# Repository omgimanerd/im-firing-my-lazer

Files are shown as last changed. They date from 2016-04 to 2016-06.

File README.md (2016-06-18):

# im-firing-my-lazer
This repository contains code used in our Modern Physics Laser Scanning Project
conducted in 2016 at Stuyvesant High School.

# Dependencies
To replicate this experiment with our Arduino setup, this project requires
pyserial.
```
pip install pyserial
```

To run the analyses on the data or to view the data, you need numpy, matplotlib, and pillow.
```
pip install numpy matplotlib pillow
```

# Experiment explanation and results
Please reference this [paper](https://github.com/omgimanerd/im-firing-my-lazer/blob/master/paper/paper.pdf)

# Creators/Authors
  - omgimanerd (Alvin Lin)
  - sachalmalick (Sachal Malick)
  - jijiglobe (Jion Fairchild)

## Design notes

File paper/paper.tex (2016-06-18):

\documentclass[letterpaper, 12pt]{article}
\renewcommand{\refname}{References and Resources}
\usepackage[utf8]{inputenc}
\usepackage{float}
\usepackage{graphicx}
\graphicspath{{pictures/}}
\usepackage{listings}
\usepackage{pgfplots}
\pgfplotsset{compat=1.9}
\usepackage[pdf]{pstricks}
\usepackage{pst-optexp}
\usepackage{hyperref}
\hypersetup{colorlinks=true,linkcolor=blue,filecolor=magenta,urlcolor=cyan}

\setlength{\parskip}{1em}

\title{Modern Physics Laser Scanning Project}
\author{Alvin Lin
  \thanks{with Jion Fairchild and Sachal Malick}}
\date{June 2016}

\begin{document}

\begin{titlepage}
\maketitle
\end{titlepage}

\begin{abstract}
This experiment was conducted in the Modern Physics class of 2016 at Stuyvesant High School. The goal was to build a laser scanner using a laser and a photometer to find its maximum achievable resolution.
\end{abstract}

\section{Experimental Setup}
\par
In this experiment, we focused a laser onto a piece of paper containing our
scanning sample and read the amount of reflected light using a photometer. The photometer displayed the amount of light it received on a digital display but also conveniently had two banana jacks that outputted a voltage proportional to the amount of light it received. This allowed us to connect an Arduino microcontroller to the photometer to read and store the voltages as we passed the scanning sample beneath the laser. To shift the sample vertically and horizontally during scanning, we 3D printed slides which we actuated using stepper motors.
\par
In order to maximize the resolution of our image, we wanted the laser beam to be as small and as focused as possible. We spaced three concave lenses in front of the laser to expand the beam, collimate it, and focus it to a point. The scanning sample would be placed at the focal point of the last concave lense. If the laser was focused on a darker point on the sample, it would reflect less light and the photometer would read a lower voltage. Conversely, if the laser was focused on a lighter point, it would reflect more light and the photometer would read a higher voltage.

\begin{pspicture}[](0,0)(14,4)
  \pnodes(2,2){A}(12,2){B}
  \pnodes(10.5,1.5){D}(10.7,2){E}(10.9,2.5){F}
  \begin{optexp}
    \optbox[position=start](A)(B){laser}
    \lens[lensradius=0.75,abspos=1,labeloffset=-1](A)(B){expands beam}
    \lens[lensradius=2.3,abspos=4](A)(B){collimates beam}
    \lens[lensradius=0.75,abspos=8](A)(B){focuses beam}
    \mirror[labeloffset=-0.7](D)(E)(F){sample}
    \drawwidebeam[beamwidth=0.2,linecolor=red]{-}(B)
  \end{optexp}
\end{pspicture}

\par
The Arduino that we used to read in the voltage values from the photometer was also used to simultaneously control the stepper motors moving the sample. For one dimensional scans, we scanned across the sample once and graphed the relative intensities as the laser passed over the sample. For two dimensional scans, we oscillated the sample in one direction while shifting it perpendicular to its direction of oscillation and mapped the relative intensies onto a 2D grid.

\begin{figure}[H]
  \centering
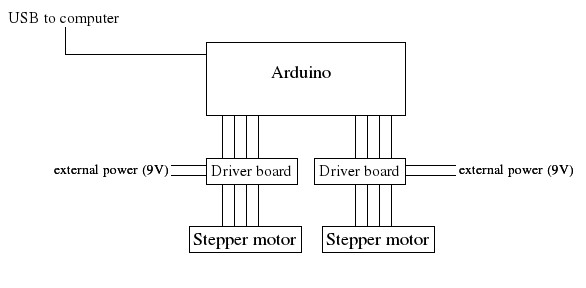
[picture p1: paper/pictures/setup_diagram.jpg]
  
  \caption{Diagram of Components}
\end{figure}

\newpage

\begin{figure}[H]
  \centering
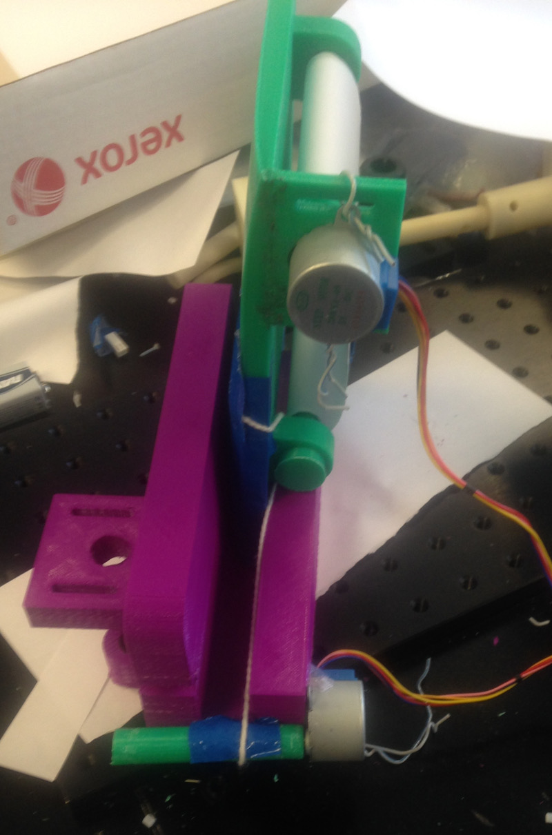
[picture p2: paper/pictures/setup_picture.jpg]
  
  \caption[caption]{3D printed components\footnotemark}
\end{figure}
\footnotetext{CADs available here:\cite{github}}

\section{Experimental Procedure}
\par
We set up various resolution test targets beneath our scanner and ran our scanner over each target. Based on the stepper motors\footnotemark
\footnotetext{USPRO 28BYJ 5V 4-phase 5-wire stepper motors \cite{amazon}}
and driver boards\footnotemark
\footnotetext{ULN2003 driver board for Arduino \cite{amazon}}
we were using, we approximated what the resolution of our setup would be. Due to the driver board's microstepping, each revolution of the motor took 512 steps. With a 0.5 inch diameter drive axle moving the sample, this means that 1 step of the motor would shift the sample $3.067962\times10^{-3}$ inches. Converting this to $\frac{lines}{mm}$:

$$ 3.067962\times10^{-3}in = 7.79262348\times10^{-2}mm $$
$$ \frac{1\ line}{7.79262348\times10^{-2}mm} \approx 12.83\frac{lines}{mm} $$

\par
This number only holds true if our laser beam is an infinitesimally small point. Since this is not the case, our actual resolution is much lower.

\section{Experimental Results for 1 Dimensional Scans}

\begin{figure}[H]
  \centering
  
  \caption[caption]{Example Resolution Test Targets (not to scale)\cite{test_chart}}
\end{figure}

\par
Running the laser scanner over the actual resolution test targets above gave us a much clearer indicator of whether or not our scanner was actually able to resolve up to 12.83 $\frac{lines}{mm}$. We ran the laser directly over the five lines in each resolution test target while reading in the values, starting with the lowest resolution.

\pgfplotstableread{scan_1.6.txt}
  \dataone
\begin{figure}[H]
  \centering
  \begin{tikzpicture}
    \begin{axis}[
      xlabel={$time$},
      ylabel={$relative\ intensity$},
      xticklabels={,,},
      yticklabels={,,}]
      \addplot[mark=none] table from \dataone;
    \end{axis}
  \end{tikzpicture}
  \caption[caption]{Scan of 1.6 $\frac{lines}{mm}$ resolution test target}
\end{figure}

\par
In figure 4, five discrete dips in the relative intensity read by the Arduino are visible as the laser passes over the 1.6 $\frac{lines}{mm}$ resolution test target. Each dip is distinguishable and corresponds to a line on the resolution test target. As long as each dip in the relative intensity is discrete for that test, we will consider it a resolvable resolution.

\pgfplotstableread{scan_1.8.txt}
  \datatwo
\begin{figure}[H]
  \centering
  \begin{tikzpicture}
    \begin{axis}[
      xlabel={$time$},
      ylabel={$relative\ intensity$},
      xticklabels={,,},
      yticklabels={,,}]
      \addplot[mark=none] table from \datatwo;
    \end{axis}
  \end{tikzpicture}
  \caption[caption]{Scan of 1.8 $\frac{lines}{mm}$ resolution test target}
\end{figure}

\pgfplotstableread{scan_2.0.txt}
  \datathree
\begin{figure}[H]
  \centering
  \begin{tikzpicture}
    \begin{axis}[
      xlabel={$time$},
      ylabel={$relative\ intensity$},
      xticklabels={,,},
      yticklabels={,,}]
      \addplot[mark=none] table from \datathree;
    \end{axis}
  \end{tikzpicture}
  \caption[caption]{Scan of 2.0 $\frac{lines}{mm}$ resolution test target}
\end{figure}

\pgfplotstableread{scan_2.2.txt}
  \datathree
\begin{figure}[H]
  \centering
  \begin{tikzpicture}
    \begin{axis}[
      xlabel={$time$},
      ylabel={$relative\ intensity$},
      xticklabels={,,},
      yticklabels={,,}]
      \addplot[mark=none] table from \datathree;
    \end{axis}
  \end{tikzpicture}
  \caption[caption]{Scan of 2.2 $\frac{lines}{mm}$ resolution test target}
\end{figure}

\pgfplotstableread{scan_2.5.txt}
  \datathree
\begin{figure}[H]
  \centering
  \begin{tikzpicture}
    \begin{axis}[
      xlabel={$time$},
      ylabel={$relative\ intensity$},
      xticklabels={,,},
      yticklabels={,,}]
      \addplot[mark=none] table from \datathree;
    \end{axis}
  \end{tikzpicture}
  \caption[caption]{Scan of 2.5 $\frac{lines}{mm}$ resolution test target}
\end{figure}

\pgfplotstableread{scan_2.8.txt}
  \datathree
\begin{figure}[H]
  \centering
  \begin{tikzpicture}
    \begin{axis}[
      xlabel={$time$},
      ylabel={$relative\ intensity$},
      xticklabels={,,},
      yticklabels={,,}]
      \addplot[mark=none] table from \datathree;
    \end{axis}
  \end{tikzpicture}
  \caption[caption]{Scan of 2.8 $\frac{lines}{mm}$ resolution test target}
\end{figure}

\pgfplotstableread{scan_3.2.txt}
  \datathree
\begin{figure}[H]
  \centering
  \begin{tikzpicture}
    \begin{axis}[
      xlabel={$time$},
      ylabel={$relative\ intensity$},
      xticklabels={,,},
      yticklabels={,,}]
      \addplot[mark=none] table from \datathree;
    \end{axis}
  \end{tikzpicture}
  \caption[caption]{Scan of 3.2 $\frac{lines}{mm}$ resolution test target}
\end{figure}

\pgfplotstableread{scan_4.0.txt}
  \datathree
\begin{figure}[H]
  \centering
  \begin{tikzpicture}
    \begin{axis}[
      xlabel={$time$},
      ylabel={$relative\ intensity$},
      xticklabels={,,},
      yticklabels={,,}]
      \addplot[mark=none] table from \datathree;
    \end{axis}
  \end{tikzpicture}
  \caption[caption]{Scan of 4.0 $\frac{lines}{mm}$ resolution test target}
\end{figure}

\section{Analysis}
\par
Figures 5 to 11 show our scan data as we increase the resolution of our test target. As the resolution increases, the variance in relative intensity between the lines and the space between them becomes muddled. It is possible to see five discrete dips only up to 3.2 $\frac{lines}{mm}$. At 4.0 $\frac{lines}{mm}$, it is no longer possible to discern five discrete dips in the relative intensity detected. Our testable scanner resolution limit, therefore, is 3.2 $\frac{lines}{mm}$.
\par
We could likely improve our resolution by focusing the laser to a smaller point. Due to human error, our lenses were probably not optimally aligned and we did not focus the laser to a small enough point. Additionally, we could improve the scanner by reducing the radius of the axle pulling the sample across the laser, which would reduce the step distance and increase the precision.

\section{Experimental Results for 2 Dimensional Scans}
\par
For two dimensional scans, instead of running the sample in one direction under the laser, we oscillated it back and forth in the $x$ direction while shifting it in the $y$ direction. This allowed us to produce a two-dimensional image of the lines on the resolution test target by mapping the values onto a 2D grid.

\begin{figure}[H]
  \centering
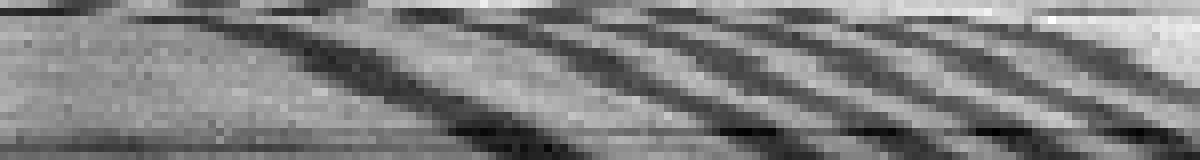
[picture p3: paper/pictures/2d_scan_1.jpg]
  
  \caption[caption]{Two Dimensional Scan of the 1.6 $\frac{lines}{mm}$ Test Target}
\end{figure}

\par
For demonstration purposes, we used a lower resolution test target so that we could produce a discernible image. We scaled the voltage received by the Arduino to a greyscale value and plotted it based on the motor's position to create the image. However, the motor would slightly drift after each oscillation, creating the slanted lines visible in the scan above.

\begin{figure}[H]
  \centering
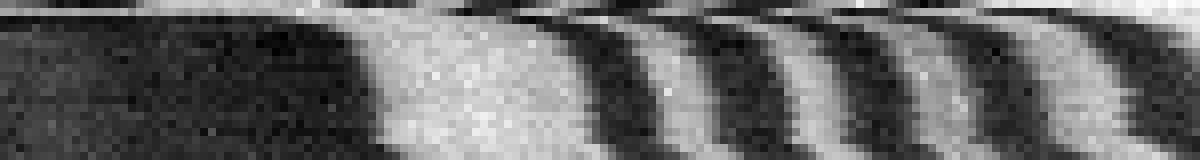
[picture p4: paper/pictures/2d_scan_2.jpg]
  
  \caption[caption]{Two Dimensional Scan with Drift Adjustment}
\end{figure}

\par
We were able to reduce some of the slanting by manually accounting for the drift in the motors. Some noise is visible in both of the scans due to the flexing of test target during scanning since it was printed on standard printer paper.

\newpage

\begin{thebibliography}{9}

  \bibitem{amazon}
  Amazon.
  \textit{USPRO 28BYJ Stepper Motors + ULN2003 Driver Board}
  \texttt{https://www.amazon.com/USPRO-Stepper-28BYJ-48-4-Phase-ULN2003/}
  \texttt{dp/B00JB22IQC}

  \bibitem{arduino}
  Arduino.
  \textit{References and Guides}\newline
  \texttt{https://www.arduino.cc/}

  \bibitem{github}
  GitHub.
  \textit{im-firing-my-lazer repository}
  Alvin Lin, 2016\newline
  \texttt{https://www.github.com/omgimanerd/im-firing-my-lazer}

  \bibitem{laser_scanning_paper}
  Peter Axelsson.
  \textit{Processing of laser scanner data - algorithms and applications}.
  Department of Geodesy and Photogrammetry, Royal Institute of Technology, Stockholm, Sweden, 1998.\newline
  \texttt{http://warnercnr.colostate.edu/~lefsky/isprs/1133.pdf}

  \bibitem{thinkquest}
  ThinkQuest.
  \textit{Lenses and optics}
  American Physical Society, 2006\newline
  \texttt{http://www.physicscentral.com/experiment/physicsquest/past/upload/}
  \texttt{pq06-Extension4.pdf}

  \bibitem{test_chart}
  USAF Test Chart
  \textit{High Definition Test Slides}
  Pyser-SGI\newline
  \texttt{http://www.pyser-sgi.com/graticules/graticules-news/usaf-test-chart-}
  \texttt{gets-higher-definition}

\end{thebibliography}

\newpage

\appendix
\section{Appendix A: Code Resources}

\subsection{Arduino code for 1 dimensional scanning}
\begin{lstlisting}[language=C]
#include <Stepper.h>

// Globals
#define BAUDRATE 9600
#define NUM_POLLS 10

#define SCAN_SPEED 60
#define SCAN_STEPS 700
#define SCAN_INTERVAL 1

Stepper motor(512, 8, 10, 9, 11);

void setup() {
  Serial.begin(BAUDRATE);
  for (int i = 8; i < 12; ++i) {
    pinMode(i, OUTPUT);
  }
  motor.setSpeed(SCAN_SPEED);
}

void loop() {
  String data = Serial.readString();
  float value_sum = 0;
  Serial.println(data);
  if (data == "begin") {
    Serial.println("{ \"type\": \"1d\" }");
    for (int i = 0; i < SCAN_STEPS; ++i) {
      value_sum = 0;
      for (int j = 0; j < NUM_POLLS; ++j) {
        value_sum += analogRead(A0);
      }
      Serial.println(value_sum / 10.0);
      motor.step(SCAN_INTERVAL);
    }
    Serial.println("end");
    motor.step(-SCAN_INTERVAL * SCAN_STEPS);
  }
}
\end{lstlisting}

\subsection{Arduino code for 2 dimensional scanning}
\begin{lstlisting}[language=C]
#include <Stepper.h>

// Globals
#define BAUDRATE 9600
#define NUM_POLLS 10

#define SCAN_SPEED 40
#define X_SCAN_STEPS 20
#define X_SCAN_INTERVAL 50
#define Y_SCAN_STEPS 150
#define Y_SCAN_INTERVAL 5

// The motor drifts some amount every y-iteration. This constant fights against that.
#define DRIFT_CONSTANT -50

Stepper x_motor(512, 4, 6, 5, 7);
Stepper y_motor(512, 8, 10, 9, 11);

void setup() {
  Serial.begin(BAUDRATE);
  for (int i = 4; i < 12; ++i) {
    pinMode(i, OUTPUT);
  }
  x_motor.setSpeed(SCAN_SPEED);
  y_motor.setSpeed(SCAN_SPEED);
}

void loop() {
  String data = Serial.readString();
  float value_sum = 0;
  Serial.println(data);
  if (data == "begin") {
    Serial.print("{ \"type\": \"2d\", \"width\": ");
    Serial.print(Y_SCAN_STEPS);
    Serial.print(", \"height\": ");
    Serial.print(X_SCAN_STEPS);
    Serial.print(" }\n");
    for (int x = 0; x < X_SCAN_STEPS; ++x) {
      for (int y = 0; y < Y_SCAN_STEPS; ++y) {
        value_sum = 0;
        for (int i = 0; i < NUM_POLLS; ++i) {
          value_sum += analogRead(A0);
          delay(2);
        }
        Serial.println(value_sum / 10.0);
        y_motor.step(Y_SCAN_INTERVAL);
      }
      y_motor.step(-(Y_SCAN_INTERVAL * Y_SCAN_STEPS - DRIFT_CONSTANT));
      x_motor.step(X_SCAN_INTERVAL);
    }
    Serial.println("end");
    x_motor.step(-X_SCAN_INTERVAL * X_SCAN_STEPS);
    y_motor.step(-Y_SCAN_INTERVAL * Y_SCAN_STEPS);
  }
}
\end{lstlisting}

\subsection{Python code to visualize the stored data}
\begin{lstlisting}[language=Python]
#!/usr/bin/python

from matplotlib import pyplot
from PIL import Image

import argparse
import json
import numpy as np

class Visualizer:

    @staticmethod
    def visualize(data):
        visualize_functions = {
            "1d": Visualizer.visualize_1d,
            "2d": Visualizer.visualize_2d
        }
        visualize_functions[data["type"]](data)

    @staticmethod
    def visualize_1d(data):
        figure = pyplot.figure()
        figure.suptitle("Intensity vs motor ticks")
        values = data["values"]
        pyplot.plot(range(len(values)), values)
        pyplot.xlabel("Motor ticks")
        pyplot.ylabel("Relative Intensity")
        pyplot.grid()
        pyplot.show()

    @staticmethod
    def _linear_scale(x, a1, a2, b1, b2):
        return ((x - a1) * (b2 - b1) / (a2 - a1)) + b1

    @staticmethod
    def _to_pil_data(values):
        low, high = min(values), max(values)
        return map(lambda x: Visualizer._linear_scale(x, low, high, 0, 255),
                   values)

    @staticmethod
    def visualize_2d(data):
        width = data["width"]
        height = data["height"]
        image = Image.new("1", (width, height))
        image.putdata(Visualizer._to_pil_data(data["values"]))
        image = image.resize((width * 8, height * 8), Image.ANTIALIAS)
        image.show()

if __name__ == "__main__":
    parser = argparse.ArgumentParser()
    parser.add_argument("filename", help="The JSON file containing the data")
    args = parser.parse_args()
    with open(args.filename) as data_file:
        Visualizer.visualize(json.loads(data_file.read().strip()))
\end{lstlisting}

\subsection{Python code to read the data from the serial port}
\begin{lstlisting}
#!/usr/bin/python

from lib.visualizer import Visualizer

import argparse
import json
import serial
import sys
import time

class Scanner():

    BAUDRATE = 9600
    AMPLIFYING_FACTOR = 3

    def __init__(self, serial):
        self.serial = serial

    @staticmethod
    def create(location):
        return Scanner(serial.Serial(location, Scanner.BAUDRATE))

    def read(self):
        return self.serial.readline().strip()

    def write(self, data):
        self.serial.write(data)

    def read_laser_info(self):
        data = {}
        values = []
        read = None
        while read != "begin":
            self.write("begin")
            read = self.read()
        while True:
            read = self.read()
            if read == "end":
                break
            print "Received %s" % read
            try:
                values.append(float(read) * 2)
            except ValueError:
                try:
                    data.update(json.loads(read))
                except:
                    continue
        data.update({
            "values": values
        })
        return data

if __name__ == "__main__":
    argparser = argparse.ArgumentParser()
    argparser.add_argument("serial_port", help="The serial port to read from")
    args = argparser.parse_args()

    print "Generating a scanner data visualization..."
    scanner = Scanner.create(args.serial_port)
    data = scanner.read_laser_info()

    Visualizer.visualize(data)

    print "Type a filename to save, otherwise press enter to exit..."
    filename = raw_input()
    if filename != "":
        with open("data/%s.json" % filename, "w") as f:
            f.write(json.dumps(data))
\end{lstlisting}

\end{document}

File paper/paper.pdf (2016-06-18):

# Modern Physics Laser Scanning Project

### Alvin Lin ∗

### June 2016

∗with Jion Fairchild and Sachal Malick

1

Abstract

This experiment was conducted in the Modern Physics class of 2016 at Stuyvesant High School. The goal was to build a laser scanner using a laser and a photometer to find its maximum achievable resolution.

## 1 Experimental Setup

In this experiment, we focused a laser onto a piece of paper containing our scanning sample and read the amount of reflected light using a photometer. The photometer displayed the amount of light it received on a digital dis-play but also conveniently had two banana jacks that outputted a voltage proportional to the amount of light it received. This allowed us to connect an Arduino microcontroller to the photometer to read and store the voltages as we passed the scanning sample beneath the laser. To shift the sample vertically and horizontally during scanning, we 3D printed slides which we actuated using stepper motors.

In order to maximize the resolution of our image, we wanted the laser beam to be as small and as focused as possible. We spaced three concave lenses in front of the laser to expand the beam, collimate it, and focus it to a point. The scanning sample would be placed at the focal point of the last concave lense. If the laser was focused on a darker point on the sample, it would reflect less light and the photometer would read a lower voltage. Conversely, if the laser was focused on a lighter point, it would reflect more light and the photometer would read a higher voltage.

laser

expands beam

collimates beam | focuses beam sample

The Arduino that we used to read in the voltage values from the photometer was also used to simultaneously control the stepper motors moving the sample. For one dimensional scans, we scanned across the sample once and graphed the relative intensities as the laser passed over the sample. For

1

two dimensional scans, we oscillated the sample in one direction while shifting it perpendicular to its direction of oscillation and mapped the relative intensies onto a 2D grid.

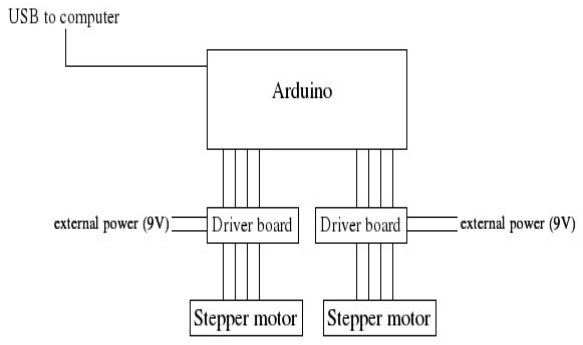
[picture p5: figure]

Figure 1: Diagram of Components

2

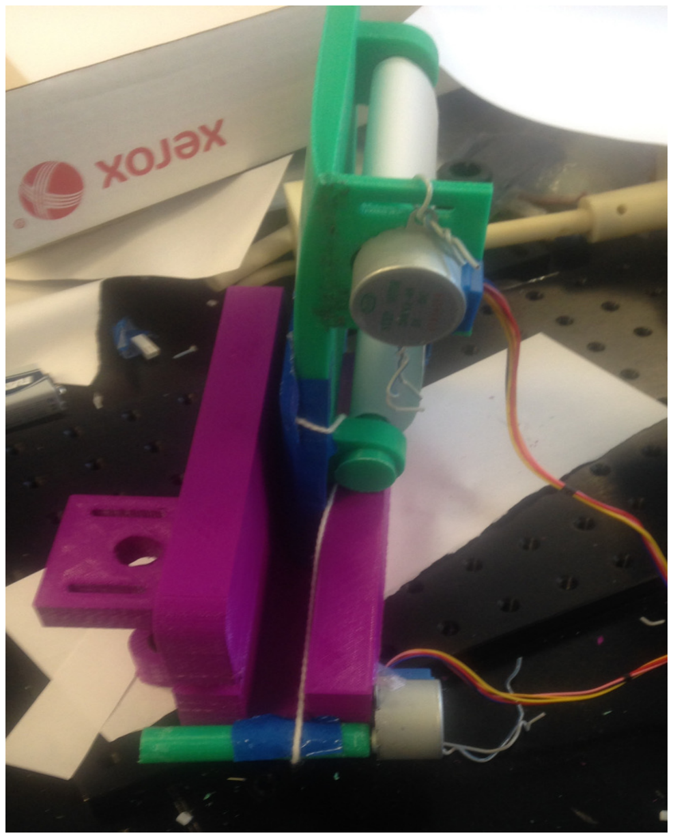
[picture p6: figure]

Figure 2: 3D printed components¹

## 2 Experimental Procedure

We set up various resolution test targets beneath our scanner and ran our scanner over each target. Based on the stepper motors² and driver boards³ we were using, we approximated what the resolution of our setup would be. Due to the driver board’s microstepping, each revolution of the motor took 512 steps. With a 0.5 inch diameter drive axle moving the sample, this means that 1 step of the motor would shift the sample 3.067962×10⁻³ inches.
Converting this to lines
mm

:

1CADs available here:[3]
2USPRO 28BYJ 5V 4-phase 5-wire stepper motors [1] 3ULN2003 driver board for Arduino [1]

3

3.067962 × 10⁻³

in = 7.79262348 × 10⁻²mm

1 line
7.79262348 × 10⁻²mm

≈ 12.83

lines
mm

This number only holds true if our laser beam is an infinitesimally small point. Since this is not the case, our actual resolution is much lower.

## 3 Experimental Results for 1 Dimensional Scans

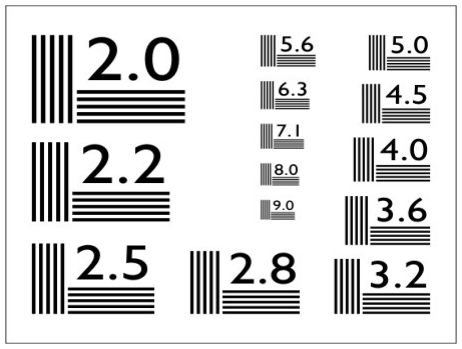
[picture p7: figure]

Figure 3: Example Resolution Test Targets (not to scale)[6]

Running the laser scanner over the actual resolution test targets above gave us a much clearer indicator of whether or not our scanner was actually able to resolve up to 12.83 lines
mm

. We ran the laser directly over the five lines in each resolution test target while reading in the values, starting with the lowest resolution.

4

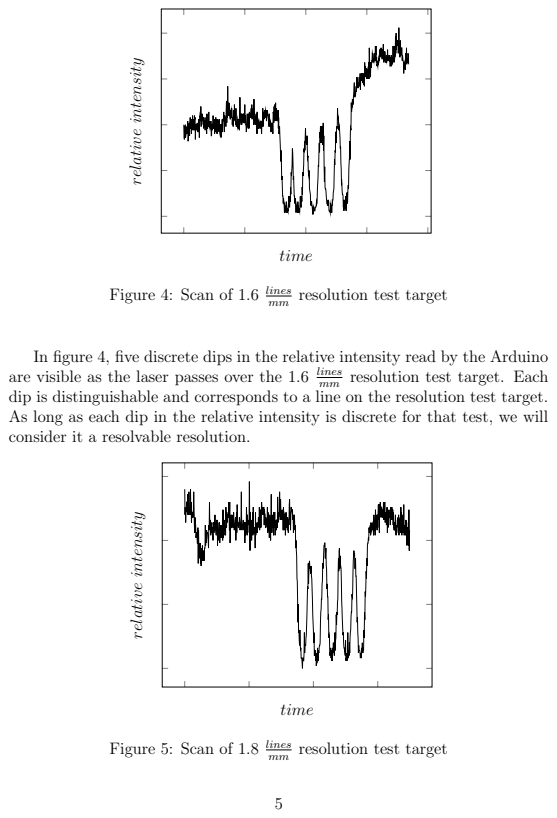
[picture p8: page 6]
time; relative intensity

Figure 4: Scan of 1.6 lines

resolution test target

In figure 4, five discrete dips in the relative intensity read by the Arduino
are visible as the laser passes over the 1.6 lines
dip is distinguishable and corresponds to a line on the resolution test target.
As long as each dip in the relative intensity is discrete for that test, we will
consider it a resolvable resolution.

resolution test target. Each

Figure 5: Scan of 1.8 lines

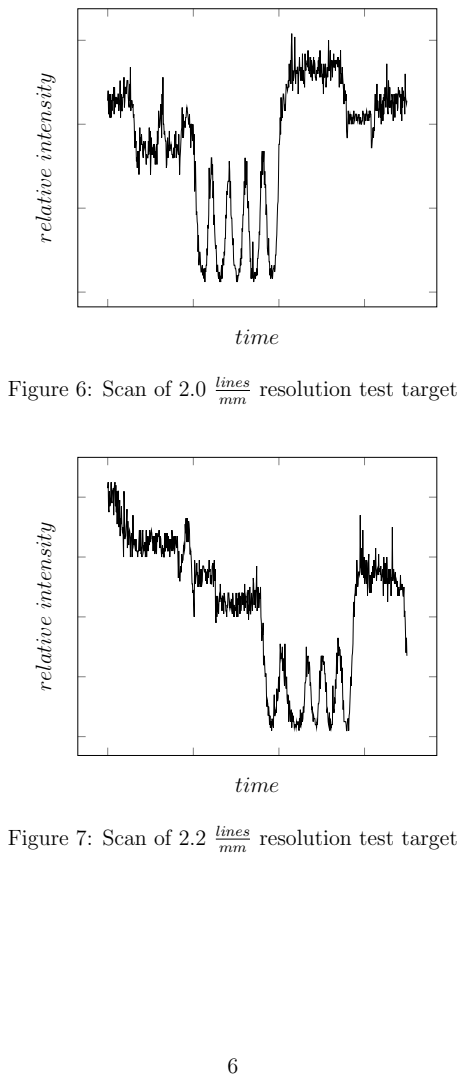
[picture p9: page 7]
time; relative intensity

Figure 6: Scan of 2.0 lines

resolution test target

Figure 7: Scan of 2.2 lines

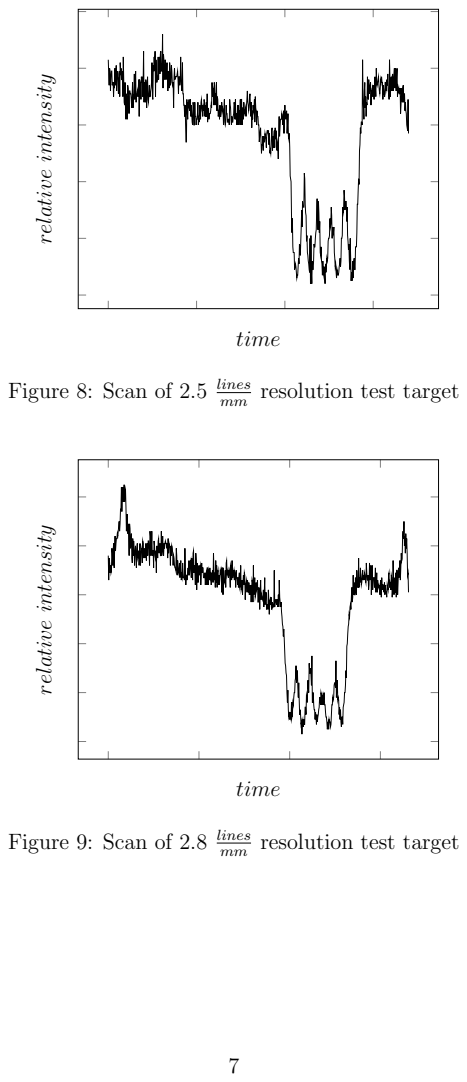
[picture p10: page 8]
time; relative intensity

Figure 8: Scan of 2.5 lines

resolution test target

Figure 9: Scan of 2.8 lines

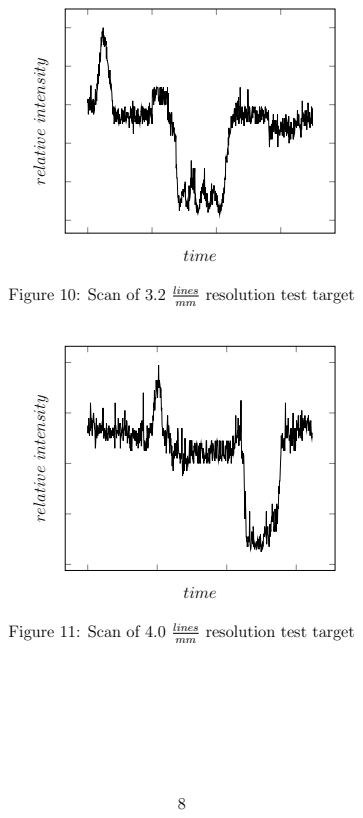
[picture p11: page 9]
time; relative intensity

Figure 10: Scan of 3.2 lines

resolution test target

Figure 11: Scan of 4.0 lines

## 4 Analysis

Figures 5 to 11 show our scan data as we increase the resolution of our test target. As the resolution increases, the variance in relative intensity between the lines and the space between them becomes muddled. It is possible to see five discrete dips only up to 3.2 lines
mm

. At 4.0 lines
mm

, it is no longer possible to discern five discrete dips in the relative intensity detected. Our testable scanner resolution limit, therefore, is 3.2 lines
mm

We could likely improve our resolution by focusing the laser to a smaller point. Due to human error, our lenses were probably not optimally aligned and we did not focus the laser to a small enough point. Additionally, we could improve the scanner by reducing the radius of the axle pulling the sample across the laser, which would reduce the step distance and increase the precision.

## 5 Experimental Results for 2 Dimensional Scans

For two dimensional scans, instead of running the sample in one direction under the laser, we oscillated it back and forth in the x direction while shifting it in the y direction. This allowed us to produce a two-dimensional image of the lines on the resolution test target by mapping the values onto a 2D grid.

9

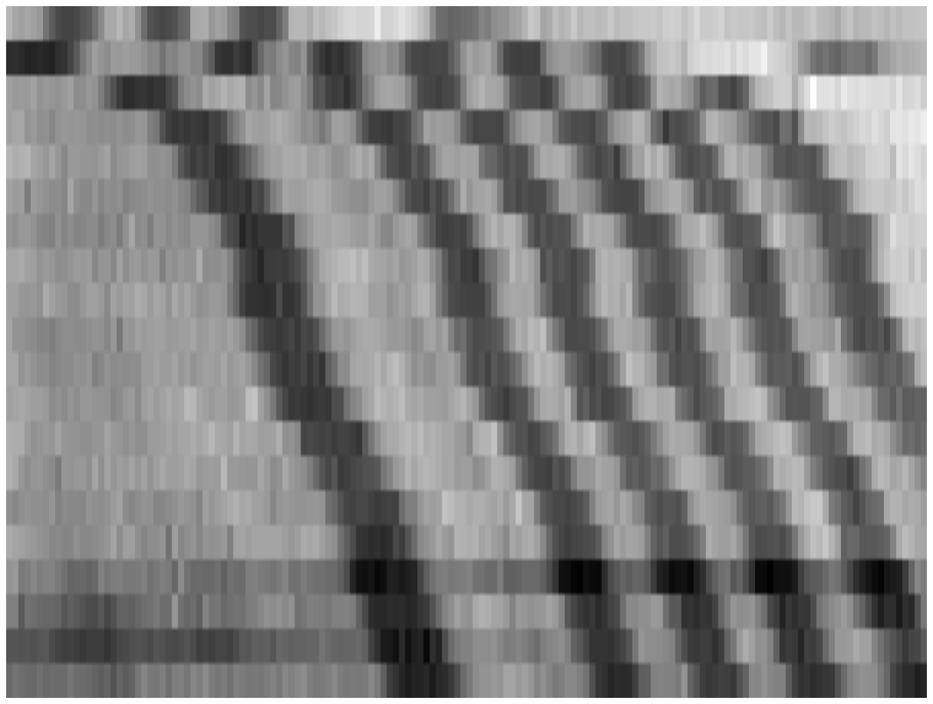
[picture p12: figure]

Figure 12: Two Dimensional Scan of the 1.6 lines
mm Test Target

For demonstration purposes, we used a lower resolution test target so that we could produce a discernible image. We scaled the voltage received by the Arduino to a greyscale value and plotted it based on the motor’s position to create the image. However, the motor would slightly drift after each oscillation, creating the slanted lines visible in the scan above.

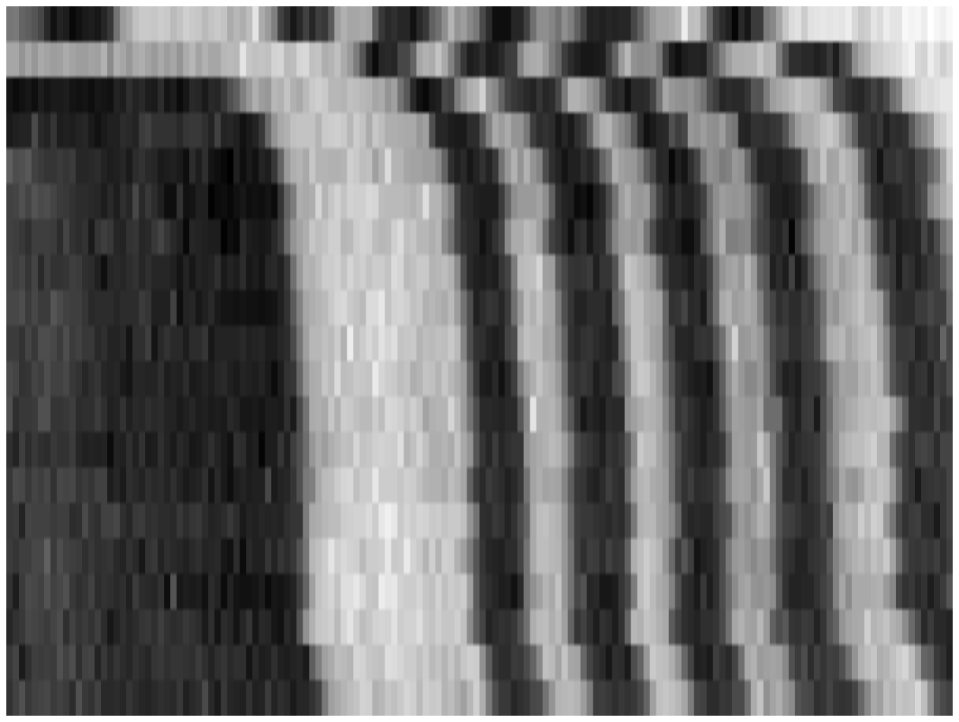
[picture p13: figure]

Figure 13: Two Dimensional Scan with Drift Adjustment

We were able to reduce some of the slanting by manually accounting for

10 the drift in the motors. Some noise is visible in both of the scans due to the flexing of test target during scanning since it was printed on standard printer paper.

11

## References and Resources

[1] Amazon. USPRO 28BYJ Stepper Motors + ULN2003 Driver Board https://www.amazon.com/USPRO-Stepper-28BYJ-48-4-Phase-ULN2003/dp/B00JB22IQC
[2] Arduino. References and Guides
https://www.arduino.cc/
[3] GitHub. im-firing-my-lazer repository Alvin Lin, 2016 https://www.github.com/omgimanerd/im-firing-my-lazer
[4] Peter Axelsson. Processing of laser scanner data - algorithms and appli-cations. Department of Geodesy and Photogrammetry, Royal Institute of Technology, Stockholm, Sweden, 1998. http://warnercnr.colostate.edu/ lefsky/isprs/1133.pdf
[5] ThinkQuest. Lenses and optics American Physical Society, 2006 http://www.physicscentral.com/experiment/physicsquest/past/upload/pq06-Extension4.pdf
[6] USAF Test Chart High Definition Test Slides Pyser-SGI http://www.pyser-sgi.com/graticules/graticules-news/usaf-test-chart-gets-higher-definition

12

## A Appendix A: Code Resources

### A.1 Arduino code for 1 dimensional scanning

#include <S teppe r . h>

// G l o b a l s
#def ine BAUDRATE 9600

#def ine NUM POLLS 10

#def ine SCAN SPEED 60

#def ine SCAN STEPS 700

#def ine SCAN INTERVAL 1

S teppe r motor (512 , 8 , 10 , 9 , 1 1 ) ;

void se tup ( ) {
S e r i a l . b egi n (BAUDRATE) ;
for ( int i = 8 ; i < 1 2; ++i ) {
| pinMode ( i , OUTPUT) ;
}
motor . s e t S p e e d (SCAN SPEED ) ;
}

void loo p ( ) {
S t ri n g data = S e r i a l . r e a d S t ri n g ( ) ; f l o a t value sum = 0 ;
S e r i a l . p r i n t l n ( data ) ;
i f ( data == ” b egi n ” ) {
| S e r i a l . p r i n t l n ( ”{ \” type \ ”: \”1d\” }” ) ; for ( int i = 0 ; i < SCAN STEPS; ++i ) { value sum = 0 ; for ( int j = 0 ; j < NUM POLLS; ++j ) { value sum += analogRead (A0 ) ; } S e r i a l . p r i n t l n ( value sum / 1 0 . 0 ) ; motor . s t e p (SCAN INTERVAL ) ;
| 13

}
S e r i a l . p r i n t l n ( ” end” ) ;
motor . s t e p (−SCAN INTERVAL ∗ SCAN STEPS ) ; }
}

### A.2 Arduino code for 2 dimensional scanning

#include <S teppe r . h>

// G l o b a l s
#def ine BAUDRATE 9600

#def ine NUM POLLS 10

#def ine SCAN SPEED 40

#def ine X SCAN STEPS 20

#def ine X SCAN INTERVAL 50 #def ine Y SCAN STEPS 150

#def ine Y SCAN INTERVAL 5

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

S teppe r x motor (512 , 4 , 6 , 5 , 7 ) ;
S teppe r y motor (512 , 8 , 10 , 9 , 1 1 ) ;

void se tup ( ) {
S e r i a l . b egi n (BAUDRATE) ;
for ( int i = 4 ; i < 1 2; ++i ) {
| pinMode ( i , OUTPUT) ;
}
x motor . s e t S p e e d (SCAN SPEED ) ; y motor . s e t S p e e d (SCAN SPEED ) ; }

void loo p ( ) {
S t ri n g data = S e r i a l . r e a d S t ri n g ( ) ;

14

f l o a t value sum = 0 ;
S e r i a l . p r i n t l n ( data ) ;
i f ( data == ” b egi n ” ) {
S e r i a l . p r i n t ( ”{ \” type \ ”: \”2d\” , \” width \ ”: ” ) ; S e r i a l . p r i n t (Y SCAN STEPS ) ;
S e r i a l . p r i n t ( ” , \” h ei g h t \ ”: ” ) ;
S e r i a l . p r i n t (X SCAN STEPS ) ;
S e r i a l . p r i n t ( ” }\n” ) ;
for ( int x = 0 ; x < X SCAN STEPS ; ++x ) { for ( int y = 0 ; y < Y SCAN STEPS ; ++y ) { value sum = 0 ;
for ( int i = 0 ; i < NUM POLLS; ++i ) { value sum += analogRead (A0 ) ;
d ela y ( 2 ) ;
}
S e r i a l . p r i n t l n ( value sum / 1 0 . 0 ) ;
y motor . s t e p (Y SCAN INTERVAL ) ;
}
y motor . s t e p (−(Y SCAN INTERVAL ∗ Y SCAN STEPS − DRIFT CONSTANT ) ) ; x motor . s t e p (X SCAN INTERVAL ) ;
}
S e r i a l . p r i n t l n ( ” end” ) ;
x motor . s t e p (−X SCAN INTERVAL ∗ X SCAN STEPS ) ; y motor . s t e p (−Y SCAN INTERVAL ∗ Y SCAN STEPS ) ; }
}

### A.3 Python code to visualize the stored data

#! / u s r / b i n / py thon

from m a t pl o tli b import p y plo t from PIL import Image

import a rg p a r s e
import j s o n
import numpy a s np

15 c l a s s V i s u a l i z e r :

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

@s ta ticme thod
def l i n e a r s c a l e ( x , a1 , a2 , b1 , b2 ) : return ( ( x − a1 ) ∗ ( b2 − b1 ) / ( a2 − a1 ) ) + b1

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

@s ta ticme thod
def v i s u a l i z e 2 d ( data ) :
| width = data [ ” width ” ] h eig h t = data [ ” h ei g h t ” ] image = Image . new ( ”1” , ( width , h ei g h t ) ) image . putdata ( V i s u a l i z e r . t o p i l d a t a ( data [ ” v al u e s ” ] ) )
| 16

image = image . r e s i z e ( ( width ∗ 8 , h ei g h t ∗ 8 ) , Image . ANTIALIAS) image . show ( )

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

### A.4 Python code to read the data from the serial port

#!/ u s r / bin / python

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

c l a s s Scanner ( ) :

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

V i s u a l i z e r . v i s u a l i z e ( data )

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

19

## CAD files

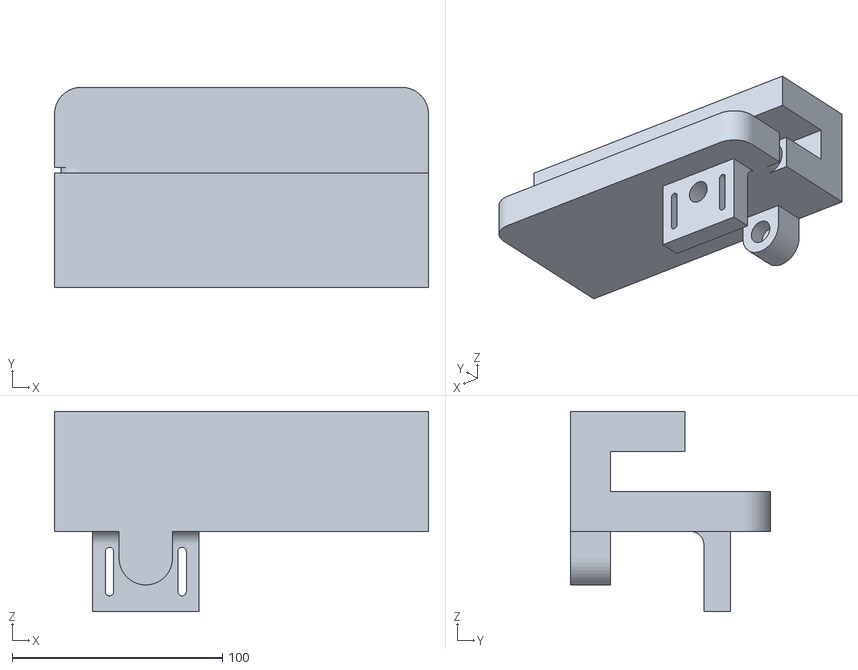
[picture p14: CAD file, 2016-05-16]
CAD/x-plate.STL
177.8 x 95.2 x 95.2

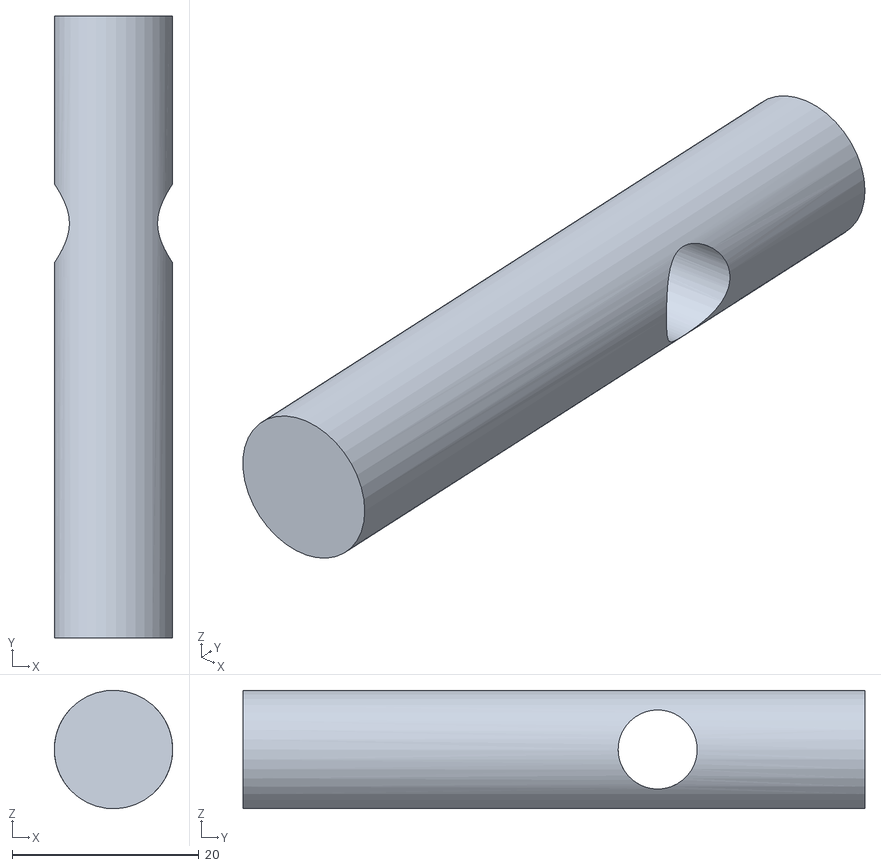
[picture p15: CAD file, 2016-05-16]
CAD/x-axle.STL
12.7 x 66.7 x 12.7

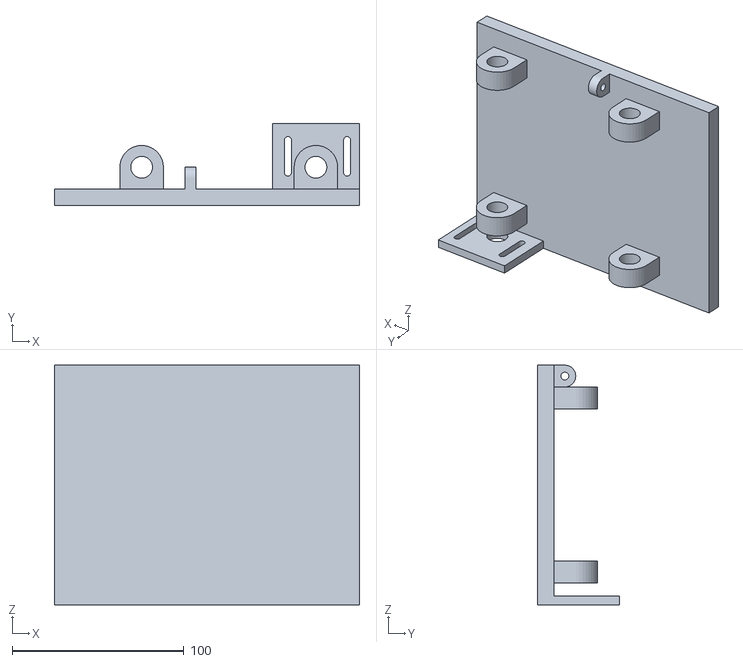
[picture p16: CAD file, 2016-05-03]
CAD/base plate.STL
177.8 x 47.6 x 139.7

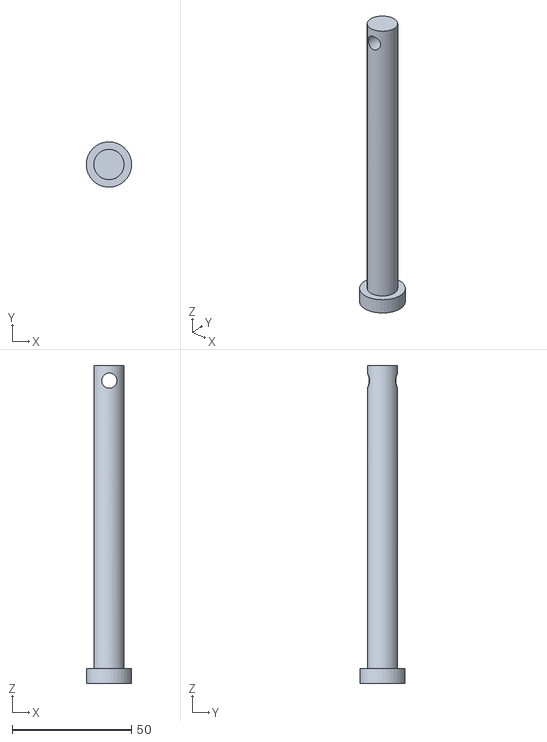
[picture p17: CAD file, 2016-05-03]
CAD/dead axle.STL
19.0 x 19.0 x 133.4

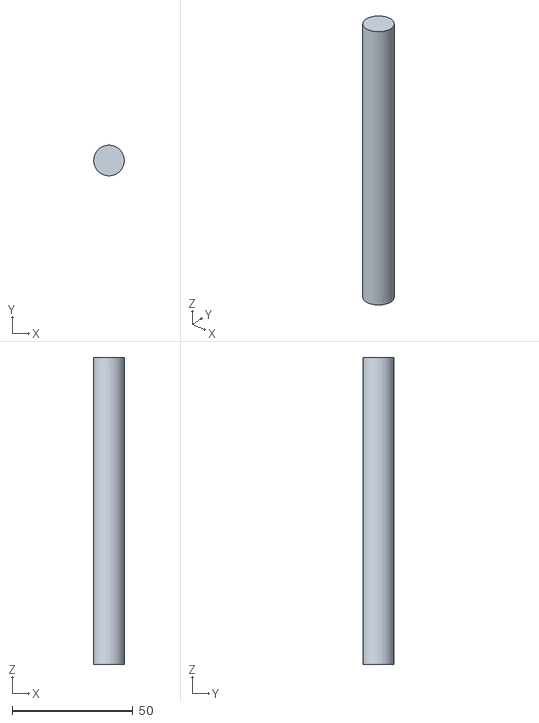
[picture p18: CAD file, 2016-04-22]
CAD/direct drive axle.STL
12.7 x 12.7 x 127.0

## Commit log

2016-04-13 laser scanner
2016-04-22 added CAD files
    [base-plate.STL, dead-axle.STL, direct-drive-axle.STL]
2016-04-24 added updated CAD files
    [base plate.SLDPRT, base plate.SLDPRT.STEP, base plate.STL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]
2016-04-24 fixed plate thickness
    [base plate.STL]
2016-05-06 clear data script, improved script to move the motor reset position upon write from computer
    [Scanner.ino, scanner.py]
2016-05-15 uploaded x-files
    [x-axle.STL, x-plate.STL]
2016-05-26 removed unneeded files
    [base plate.SLDPRT, base plate.SLDPRT.STEP, cartesian plane.SLDASM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]
